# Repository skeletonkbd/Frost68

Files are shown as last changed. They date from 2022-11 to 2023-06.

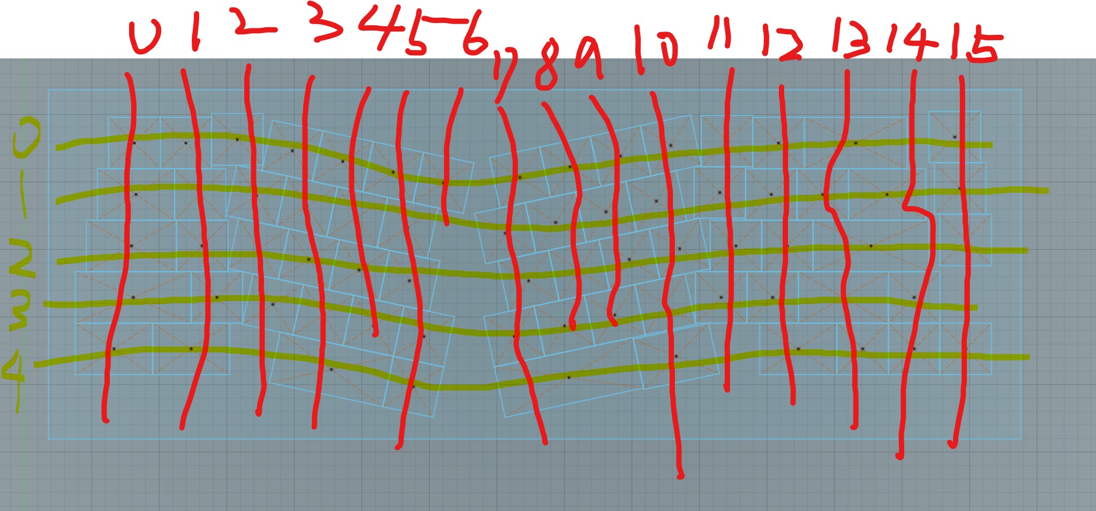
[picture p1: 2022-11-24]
PCB/keymatrix.jpg

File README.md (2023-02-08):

# Frost68



アクリル積層ケースを使った Alice 配列のキーボードです。（開発時名称: Skeleton68rev2）

Firmware: https://github.com/skeletonkbd/qmk_firmware/tree/Frost68/keyboards/skeletonkbd/frost68









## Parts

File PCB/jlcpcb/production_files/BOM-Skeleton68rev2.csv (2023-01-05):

Comment | Designator | Footprint | LCSC
1k | R1,R2,R7 | R_0402_1005Metric | C11702
W25Q128JVS | U1 | SOIC-8_5.23x5.23mm_P1.27mm | C131025
100nF | C1,C10,C11,C12,C13,C14,C15,C5,C6,C9 | C_0402_1005Metric | C1525
10uF | C7 | C_0402_1005Metric | C15525
22pF | C2,C3 | C_0402_1005Metric | C1555
USB_C_Receptacle_USB2.0 | J1 | USB_C_Receptacle_HRO_TYPE-C-31-M-12 | C165948
RP2040 | U3 | QFN-56-1EP_7x7mm_P0.4mm_EP3.2x3.2mm | C2040
27 | R5,R6 | R_0603_1608Metric | C25190
10k | R8,R9 | R_0603_1608Metric | C25804
5k1 | R3,R4 | R_0402_1005Metric | C25905
SW_Push | SW1,SW10,SW11,SW12,SW13,SW14,SW15,SW16,SW17,SW18,SW19,SW2,SW20,SW21,SW22,SW23,SW24,SW25,SW26,SW27,SW28,SW29,SW3,SW30,SW31,SW32,SW33,SW34,SW35,SW36,SW37,SW38,SW39,SW4,SW40,SW41,SW42,SW43,SW44,SW45,SW46,SW47,SW48,SW49,SW5,SW50,SW51,SW52,SW53,SW54,SW55,SW56,SW57,SW58,SW59,SW6,SW60,SW61,SW62,SW63,SW64,SW65,SW66,SW67,SW68,SW7,SW8,SW9 | MX-Hotswap-1U | C2803348
USBLC6-2SC6 | U2 | SOT-23-6 | C2827654
SW_Push | TS1,TS2 | SW_SPST_SKQG_WithStem | C318884
BSS138 | Q1 | SOT-23 | C400505
SK6812mini-e | LED1,LED10,LED11,LED12,LED13,LED14,LED15,LED16,LED17,LED18,LED19,LED2,LED20,LED21,LED22,LED23,LED24,LED25,LED26,LED27,LED28,LED29,LED3,LED30,LED31,LED32,LED33,LED34,LED35,LED36,LED37,LED38,LED39,LED4,LED40,LED41,LED42,LED43,LED44,LED45,LED46,LED47,LED48,LED49,LED5,LED50,LED51,LED52,LED53,LED54,LED55,LED56,LED57,LED58,LED59,LED6,LED60,LED61,LED62,LED63,LED64,LED65,LED66,LED67,LED68,LED7,LED8,LED9 | SK6812-MINI-E | C5149201
1uF | C16,C17,C4,C8 | C_0402_1005Metric | C52923
XC6206PxxxMR | U4 | SOT-23 | C5446
500mA | F1 | Fuse_1206_3216Metric | C70076
1N4148W | D1,D10,D11,D12,D13,D14,D15,D16,D17,D18,D19,D2,D20,D21,D22,D23,D24,D25,D26,D27,D28,D29,D3,D30,D31,D32,D33,D34,D35,D36,D37,D38,D39,D4,D40,D41,D42,D43,D44,D45,D46,D47,D48,D49,D5,D50,D51,D52,D53,D54,D55,D56,D57,D58,D59,D6,D60,D61,D62,D63,D64,D65,D66,D67,D68,D7,D8,D9 | D_SOD-123 | C81598
12MHz | Y1 | Crystal_SMD_3225-4Pin_3.2x2.5mm | C9002

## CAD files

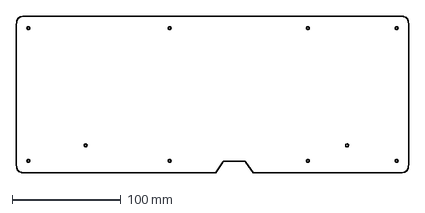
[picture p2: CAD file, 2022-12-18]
Case/dxf/01_bottom.dxf
360.0 x 143.9 mm

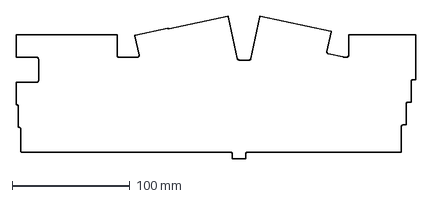
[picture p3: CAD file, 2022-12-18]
PCB/dxf/outline.dxf
339.1 x 121.0 mm

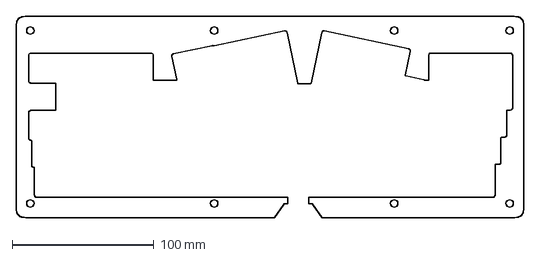
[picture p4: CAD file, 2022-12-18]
Case/dxf/02_lower-middle.dxf
358.0 x 141.9 mm

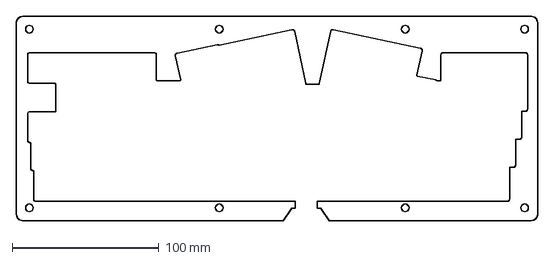
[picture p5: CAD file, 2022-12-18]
Case/dxf/03_upper-middle.dxf
356.0 x 139.9 mm

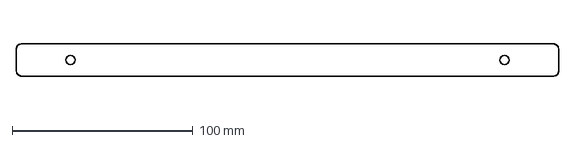
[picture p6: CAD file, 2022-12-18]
Case/dxf/feet1.dxf
300.0 x 18.0 mm

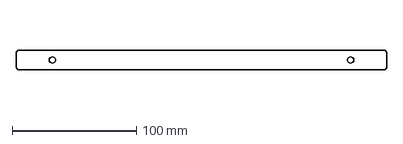
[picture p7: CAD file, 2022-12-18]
Case/dxf/feet2.dxf
298.0 x 16.0 mm

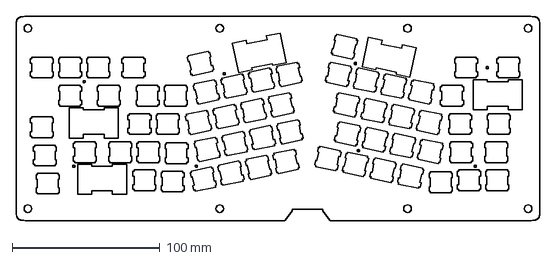
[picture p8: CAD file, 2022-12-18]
Case/dxf/04_mount.dxf
354.0 x 137.9 mm

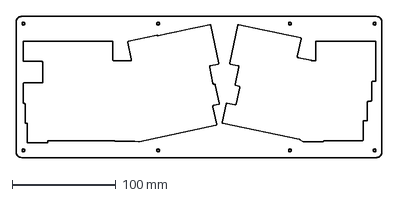
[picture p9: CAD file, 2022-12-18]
Case/dxf/05_top.dxf
352.0 x 135.9 mm

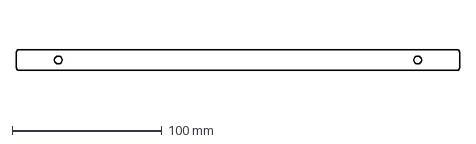
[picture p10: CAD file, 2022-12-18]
Case/dxf/feet3.dxf
296.0 x 14.0 mm

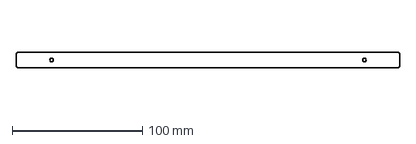
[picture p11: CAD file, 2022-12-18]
Case/dxf/feet4.dxf
294.0 x 12.0 mm

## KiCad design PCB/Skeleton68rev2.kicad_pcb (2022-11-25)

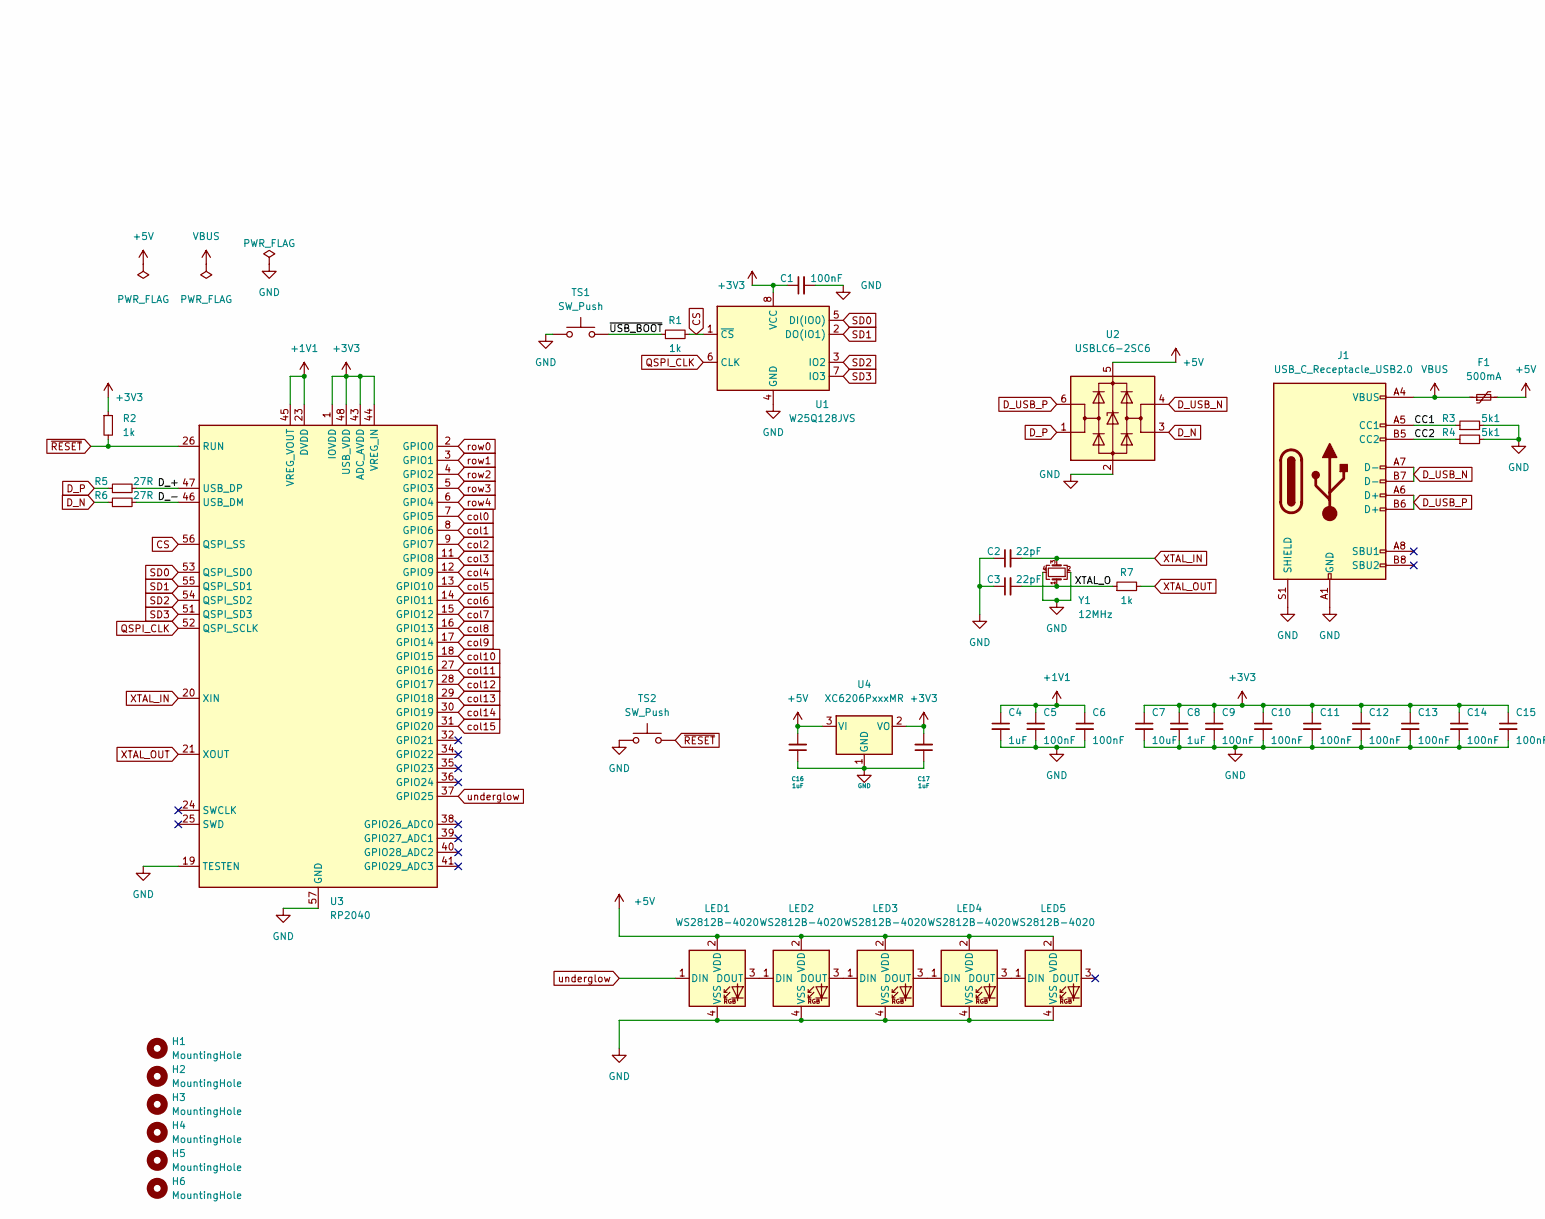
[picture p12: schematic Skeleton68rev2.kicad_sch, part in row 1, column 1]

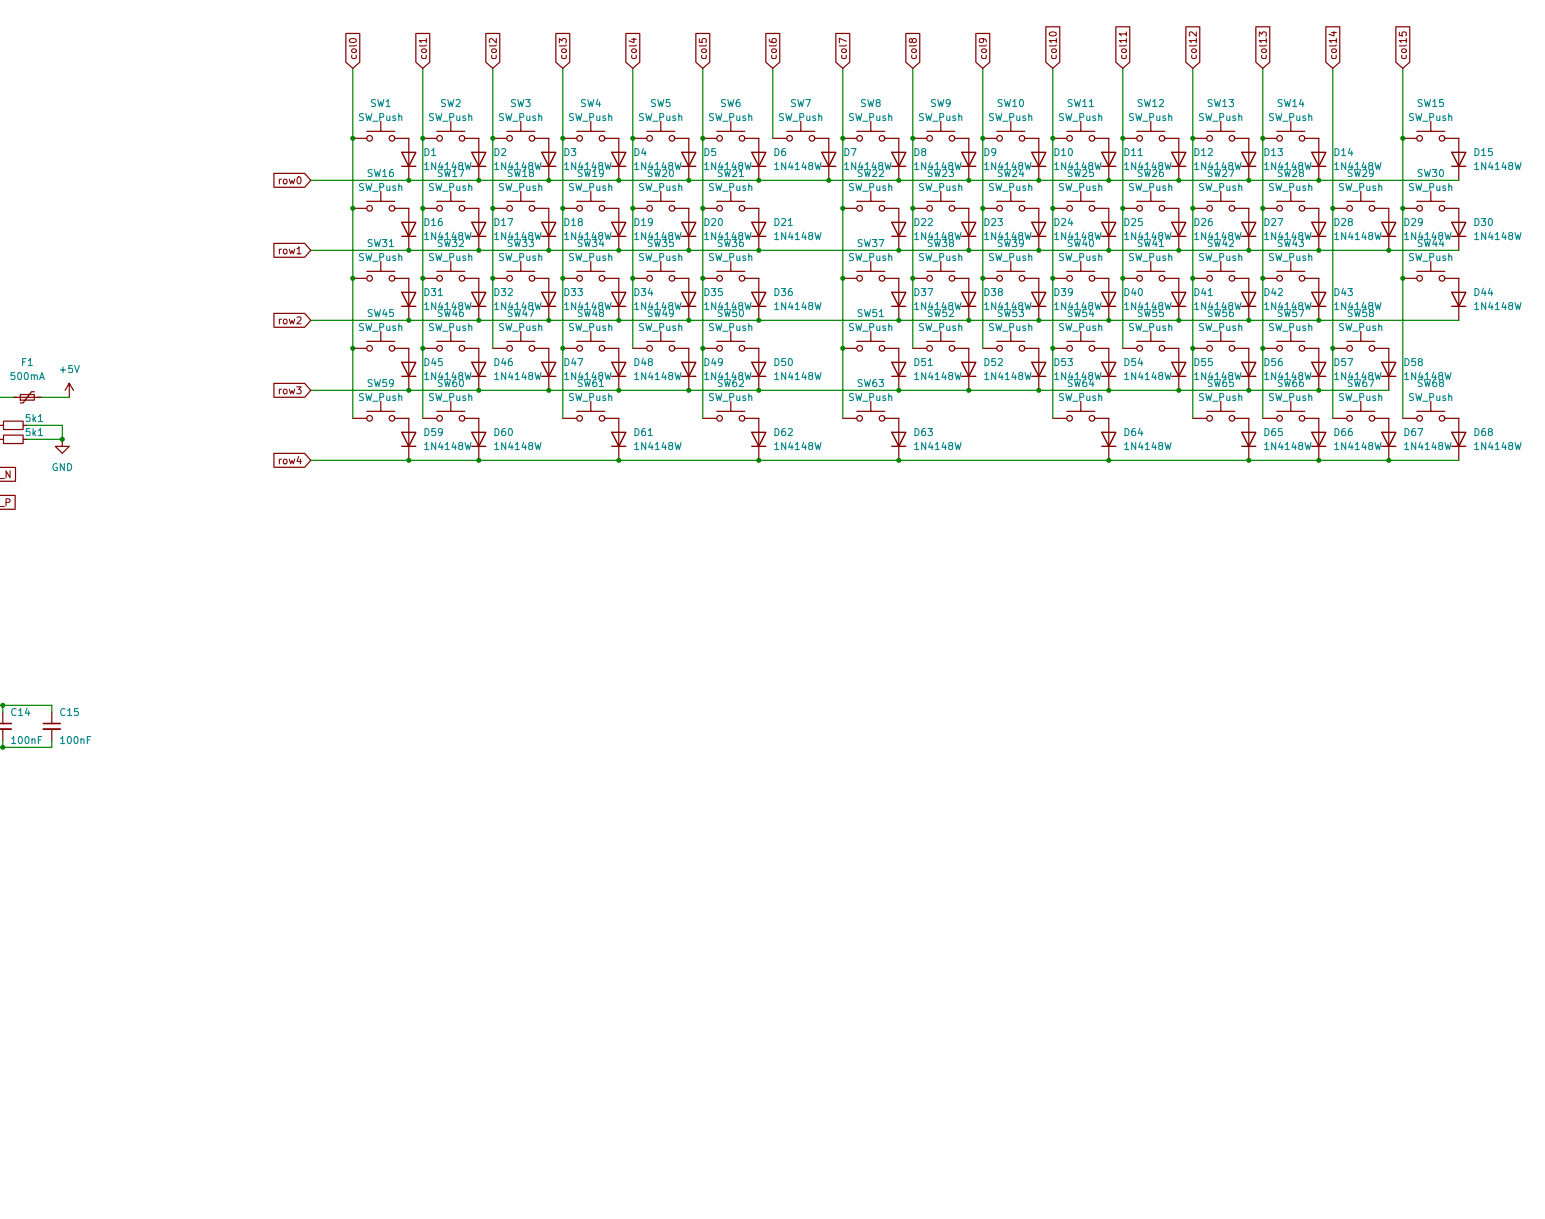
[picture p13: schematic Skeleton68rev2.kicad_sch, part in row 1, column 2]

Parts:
C1, C5, C6, C9, C10, C11, C12, C13, C14, C15: 100nF; C_0402_1005Metric; MPN CL05B104KO5NNNC; LCSC C1525
C2, C3: 22pF; C_0402_1005Metric; MPN 0402CG220J500NT; LCSC C1555
C4, C8, C16, C17: 1uF; C_0402_1005Metric; MPN CL05A105KA5NQNC; LCSC C52923
C7: 10uF; C_0402_1005Metric; MPN CL05A106MQ5NUNC; LCSC C15525
D1, D2, D3, D4, D5, D6, D7, D8, D9, D10, D11, D12, D13, D14, D15, D16, D17, D18, D19, D20, D21, D22, D23, D24, D25, D26, D27, D28, D29, D30, D31, D32, D33, D34, D35, D36, D37, D38, D39, D40, D41, D42, D43, D44, D45, D46, D47, D48, D49, D50, D51, D52, D53, D54, D55, D56, D57, D58, D59, D60, D61, D62, D63, D64, D65, D66, D67, D68: 1N4148W; D_SOD-123
F1: 500mA; Fuse_1206_3216Metric; MPN nSMD050-24V; LCSC C70076
H1, H2, H3, H4, H5, H6: MountingHole; MountingHole_2.2mm_M2
J1: USB_C_Receptacle_USB2.0; USB_C_Receptacle_HRO_TYPE-C-31-M-12; MPN TYPE-C-31-M-12; LCSC C165948
LED1, LED2, LED3, LED4, LED5: WS2812B-4020
R1, R2, R7: 1k; R_0402_1005Metric; MPN 0402WGF1001TCE; LCSC C11702
R3, R4: 5k1; R_0402_1005Metric; MPN 0402WGF5101TCE; LCSC C25905
R5, R6: 27R; R_0603_1608Metric; MPN 0603WAF270JT5E; LCSC C25190
SW1, SW2, SW3, SW4, SW5, SW6, SW7, SW8, SW9, SW10, SW11, SW12, SW13, SW14, SW15, SW16, SW17, SW18, SW19, SW20, SW21, SW22, SW23, SW24, SW25, SW26, SW27, SW28, SW29, SW30, SW31, SW32, SW33, SW34, SW35, SW36, SW37, SW38, SW39, SW40, SW41, SW42, SW43, SW44, SW45, SW46, SW47, SW48, SW49, SW50, SW51, SW52, SW53, SW54, SW55, SW56, SW57, SW58, SW59, SW60, SW61, SW62, SW63, SW64, SW65, SW66, SW67, SW68: SW_Push; MX-Hotswap-1U
TS1, TS2: SW_Push; SW_SPST_SKQG_WithStem; MPN SKQGABE010; LCSC C318884
U1: W25Q128JVS; SOIC-8_5.23x5.23mm_P1.27mm; MPN W25Q16JVSSIQ; LCSC C131025
U2: USBLC6-2SC6; SOT-23-6; MPN USBLC6-2SC6; LCSC C2827654
U3: RP2040; QFN-56-1EP_7x7mm_P0.4mm_EP3.2x3.2mm
U4: XC6206PxxxMR; SOT-23; MPN XC6206P332MR; LCSC C5446
Y1: 12MHz; Crystal_SMD_3225-4Pin_3.2x2.5mm; MPN X322512MSB4SI; LCSC C9002

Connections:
+1V1: C4.1, C5.1, C6.1, U3.23 (DVDD), U3.45 (VREG_VOUT), U3.50 (DVDD)
+3V3: C1.1, C7.1, C8.1, C9.1, C10.1, C11.1, C12.1, C13.1, C14.1, C15.1, C17.2, R2.1, U1.8 (VCC), U3.1 (IOVDD), U3.10 (IOVDD), U3.22 (IOVDD), U3.33 (IOVDD), U3.42 (IOVDD), U3.43 (ADC_AVDD), U3.44 (VREG_IN), U3.48 (USB_VDD), U3.49 (IOVDD), U4.2 (VO)
+5V: C16.2, F1.2, LED1.2 (VDD), LED2.2 (VDD), LED3.2 (VDD), LED4.2 (VDD), LED5.2 (VDD), U2.5 (VBUS), U4.3 (VI)
/CC1: J1.A5 (CC1), R3.1
/CC2: J1.B5 (CC2), R4.1
/D_+: R5.2, U3.47 (USB_DP)
/D_-: R6.2, U3.46 (USB_DM)
/XTAL_O: C3.2, R7.1, Y1.1
/~USB_BOOT: R1.1, TS1.2
CS: R1.2, U1.1 (~CS), U3.56 (QSPI_SS)
D_N: R6.1, U2.3 (I/O2)
D_P: R5.1, U2.1 (I/O1)
D_USB_N: J1.A7 (D-), J1.B7 (D-), U2.4 (I/O2)
D_USB_P: J1.A6 (D+), J1.B6 (D+), U2.6 (I/O1)
GND: C1.2, C2.1, C3.1, C4.2, C5.2, C6.2, C7.2, C8.2, C9.2, C10.2, C11.2, C12.2, C13.2, C14.2, C15.2, C16.1, C17.1, J1.A1 (GND), J1.A12 (GND), J1.B1 (GND), J1.B12 (GND), J1.S1 (SHIELD), LED1.4 (VSS), LED2.4 (VSS), LED3.4 (VSS), LED4.4 (VSS), LED5.4 (VSS), R3.2, R4.2, TS1.1, TS2.1, U1.4 (GND), U2.2 (GND), U3.19 (TESTEN), U3.57 (GND), U4.1 (GND), Y1.2, Y1.4
unnamed: D1.2 (A), SW1.2
unnamed: D2.2 (A), SW2.2
unnamed: D3.2 (A), SW3.2
unnamed: D4.2 (A), SW4.2
unnamed: D5.2 (A), SW5.2
unnamed: D6.2 (A), SW6.2
unnamed: D7.2 (A), SW7.2
unnamed: D8.2 (A), SW8.2
unnamed: D9.2 (A), SW9.2
unnamed: D10.2 (A), SW10.2
unnamed: D11.2 (A), SW11.2
unnamed: D12.2 (A), SW12.2
unnamed: D13.2 (A), SW13.2
unnamed: D14.2 (A), SW14.2
unnamed: D15.2 (A), SW15.2
unnamed: D16.2 (A), SW16.2
unnamed: D17.2 (A), SW17.2
unnamed: D18.2 (A), SW18.2
unnamed: D19.2 (A), SW19.2
unnamed: D20.2 (A), SW20.2
unnamed: D21.2 (A), SW21.2
unnamed: D22.2 (A), SW22.2
unnamed: D23.2 (A), SW23.2
unnamed: D24.2 (A), SW24.2
unnamed: D25.2 (A), SW25.2
unnamed: D26.2 (A), SW26.2
unnamed: D27.2 (A), SW27.2
unnamed: D28.2 (A), SW28.2
unnamed: D29.2 (A), SW29.2
unnamed: D30.2 (A), SW30.2
unnamed: D31.2 (A), SW31.2
unnamed: D32.2 (A), SW32.2
unnamed: D33.2 (A), SW33.2
unnamed: D34.2 (A), SW34.2
unnamed: D35.2 (A), SW35.2
unnamed: D36.2 (A), SW36.2
unnamed: D37.2 (A), SW37.2
unnamed: D38.2 (A), SW38.2
unnamed: D39.2 (A), SW39.2
unnamed: D40.2 (A), SW40.2
unnamed: D41.2 (A), SW41.2
unnamed: D42.2 (A), SW42.2
unnamed: D43.2 (A), SW43.2
unnamed: D44.2 (A), SW44.2
unnamed: D45.2 (A), SW45.2
unnamed: D46.2 (A), SW46.2
unnamed: D47.2 (A), SW47.2
unnamed: D48.2 (A), SW48.2
unnamed: D49.2 (A), SW49.2
unnamed: D50.2 (A), SW50.2
unnamed: D51.2 (A), SW51.2
unnamed: D52.2 (A), SW52.2
unnamed: D53.2 (A), SW53.2
unnamed: D54.2 (A), SW54.2
unnamed: D55.2 (A), SW55.2
unnamed: D56.2 (A), SW56.2
unnamed: D57.2 (A), SW57.2
unnamed: D58.2 (A), SW58.2
unnamed: D59.2 (A), SW59.2
unnamed: D60.2 (A), SW60.2
unnamed: D61.2 (A), SW61.2
unnamed: D62.2 (A), SW62.2
unnamed: D63.2 (A), SW63.2
unnamed: D64.2 (A), SW64.2
unnamed: D65.2 (A), SW65.2
unnamed: D66.2 (A), SW66.2
unnamed: D67.2 (A), SW67.2
unnamed: D68.2 (A), SW68.2
unnamed: LED1.3 (DOUT), LED2.1 (DIN)
unnamed: LED2.3 (DOUT), LED3.1 (DIN)
unnamed: LED3.3 (DOUT), LED4.1 (DIN)
unnamed: LED4.3 (DOUT), LED5.1 (DIN)
QSPI_CLK: U1.6 (CLK), U3.52 (QSPI_SCLK)
SD0: U1.5 (DI(IO0)), U3.53 (QSPI_SD0)
SD1: U1.2 (DO(IO1)), U3.55 (QSPI_SD1)
SD2: U1.3 (IO2), U3.54 (QSPI_SD2)
SD3: U1.7 (IO3), U3.51 (QSPI_SD3)
VBUS: F1.1, J1.A4 (VBUS), J1.A9 (VBUS), J1.B4 (VBUS), J1.B9 (VBUS)
XTAL_IN: C2.2, U3.20 (XIN), Y1.3
XTAL_OUT: R7.2, U3.21 (XOUT)
col0: SW1.1, SW16.1, SW31.1, SW45.1, SW59.1, U3.7 (GPIO5)
col1: SW2.1, SW17.1, SW32.1, SW46.1, SW60.1, U3.8 (GPIO6)
col2: SW3.1, SW18.1, SW33.1, SW47.1, U3.9 (GPIO7)
col3: SW4.1, SW19.1, SW34.1, SW48.1, SW61.1, U3.11 (GPIO8)
col4: SW5.1, SW20.1, SW35.1, SW49.1, U3.12 (GPIO9)
col5: SW6.1, SW21.1, SW36.1, SW50.1, SW62.1, U3.13 (GPIO10)
col6: SW7.1, U3.14 (GPIO11)
col7: SW8.1, SW22.1, SW37.1, SW51.1, SW63.1, U3.15 (GPIO12)
col8: SW9.1, SW23.1, SW38.1, SW52.1, U3.16 (GPIO13)
col9: SW10.1, SW24.1, SW39.1, SW53.1, U3.17 (GPIO14)
col10: SW11.1, SW25.1, SW40.1, SW54.1, SW64.1, U3.18 (GPIO15)
col11: SW12.1, SW26.1, SW41.1, SW55.1, U3.27 (GPIO16)
col12: SW13.1, SW27.1, SW42.1, SW56.1, SW65.1, U3.28 (GPIO17)
col13: SW14.1, SW28.1, SW43.1, SW57.1, SW66.1, U3.29 (GPIO18)
col14: SW29.1, SW58.1, SW67.1, U3.30 (GPIO19)
col15: SW15.1, SW30.1, SW44.1, SW68.1, U3.31 (GPIO20)
row0: D1.1 (K), D2.1 (K), D3.1 (K), D4.1 (K), D5.1 (K), D6.1 (K), D7.1 (K), D8.1 (K), D9.1 (K), D10.1 (K), D11.1 (K), D12.1 (K), D13.1 (K), D14.1 (K), D15.1 (K), U3.2 (GPIO0)
row1: D16.1 (K), D17.1 (K), D18.1 (K), D19.1 (K), D20.1 (K), D21.1 (K), D22.1 (K), D23.1 (K), D24.1 (K), D25.1 (K), D26.1 (K), D27.1 (K), D28.1 (K), D29.1 (K), D30.1 (K), U3.3 (GPIO1)
row2: D31.1 (K), D32.1 (K), D33.1 (K), D34.1 (K), D35.1 (K), D36.1 (K), D37.1 (K), D38.1 (K), D39.1 (K), D40.1 (K), D41.1 (K), D42.1 (K), D43.1 (K), D44.1 (K), U3.4 (GPIO2)
row3: D45.1 (K), D46.1 (K), D47.1 (K), D48.1 (K), D49.1 (K), D50.1 (K), D51.1 (K), D52.1 (K), D53.1 (K), D54.1 (K), D55.1 (K), D56.1 (K), D57.1 (K), D58.1 (K), U3.5 (GPIO3)
row4: D59.1 (K), D60.1 (K), D61.1 (K), D62.1 (K), D63.1 (K), D64.1 (K), D65.1 (K), D66.1 (K), D67.1 (K), D68.1 (K), U3.6 (GPIO4)
underglow: LED1.1 (DIN), U3.37 (GPIO25)
~RESET: R2.2, TS2.2, U3.26 (RUN)

Board: 2 copper layers, 180 parts (1 on the bottom side), 118 nets, no tracks yet.

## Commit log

2022-11-24 回路図作成
    [Skeleton68rev2.kicad_pcb, Skeleton68rev2.kicad_sch]
2022-11-25 ライセンス変更
    [Skeleton68rev2.kicad_pcb, outline.dxf]
2022-12-18 side mounted LEDs
    [01_bottom.dxf, 02_lower-middle.dxf, 03_upper-middle.dxf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]
2023-02-06 Add Plate
    [BOM-Skeleton68rev2_SwitchPlate.csv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]
2023-06-13 extend sk6812mini-e holes
    [BOM-Skeleton68rev2_SwitchPlate.csv, Skeleton68rev2.kicad_sch, Skeleton68rev2_2.dsn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]

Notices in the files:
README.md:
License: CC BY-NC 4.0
